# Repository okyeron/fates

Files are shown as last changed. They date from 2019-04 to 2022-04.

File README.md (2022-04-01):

# Important - regarding norns software updates
If you are on a version of norns before 200218 ***DO NOT*** run the on device SYSTEM > UPDATE from the norns menu. 

If you're still on an old version like this - back up your scripts and install from a new (2022) disk image.

# Fates DAC board for Raspberry Pi

Fates is an audio and UI platform for Raspberry Pi 3 Model B+ and Pi 4 Model B that provides a stereo audio codec with headphone driver, 3 (or 4) encoders, 3 buttons, a 128x64 OLED display, 2x audio ins, and 2x audio outs. 

Fates is fully compatible with the [monome norns](<https://github.com/monome/norns>) software ecosystem. A “DIY norns” if you like. Once installed, Fates can be used with the primary norns codebase, without any branches or mods.

Fates can also be used directly with Orac 2.0 (puredata) and also with other Raspberry Pi audio projects like PatchboxOS, etc.

NOTE - this install and norns software has been tested mostly on the Pi3b+ and Pi4b. It may not work perfectly on older/slower Pi models (3b, etc.) and may need different configuration. 

### Specs:

- WM8731 stereo audio codec with headphone driver
- NHD-2.7-12864WDW3 128x64 grayscale OLED display
- 3 pushbuttons
- 3 rotary encoders (optional 4th encoder for Orac or other software)
- 2x 1/8in inputs
- 2x 1/8in outputs
- 1/8in stereo headphone out

Fates was designed for Raspberry Pi 3 Model B+ and Raspberry Pi 4 Model B. It’s not been performance tested with earlier Raspberry PI models.

For Raspberry Pi 4, Fates includes a USB-C power jack which fixes the Pi4 issue with "e-marked" USB-C cables not powering the device.

Fates can be powered either from it's own USB-C power jack, or the Raspberry Pi power jack (but NOT both).

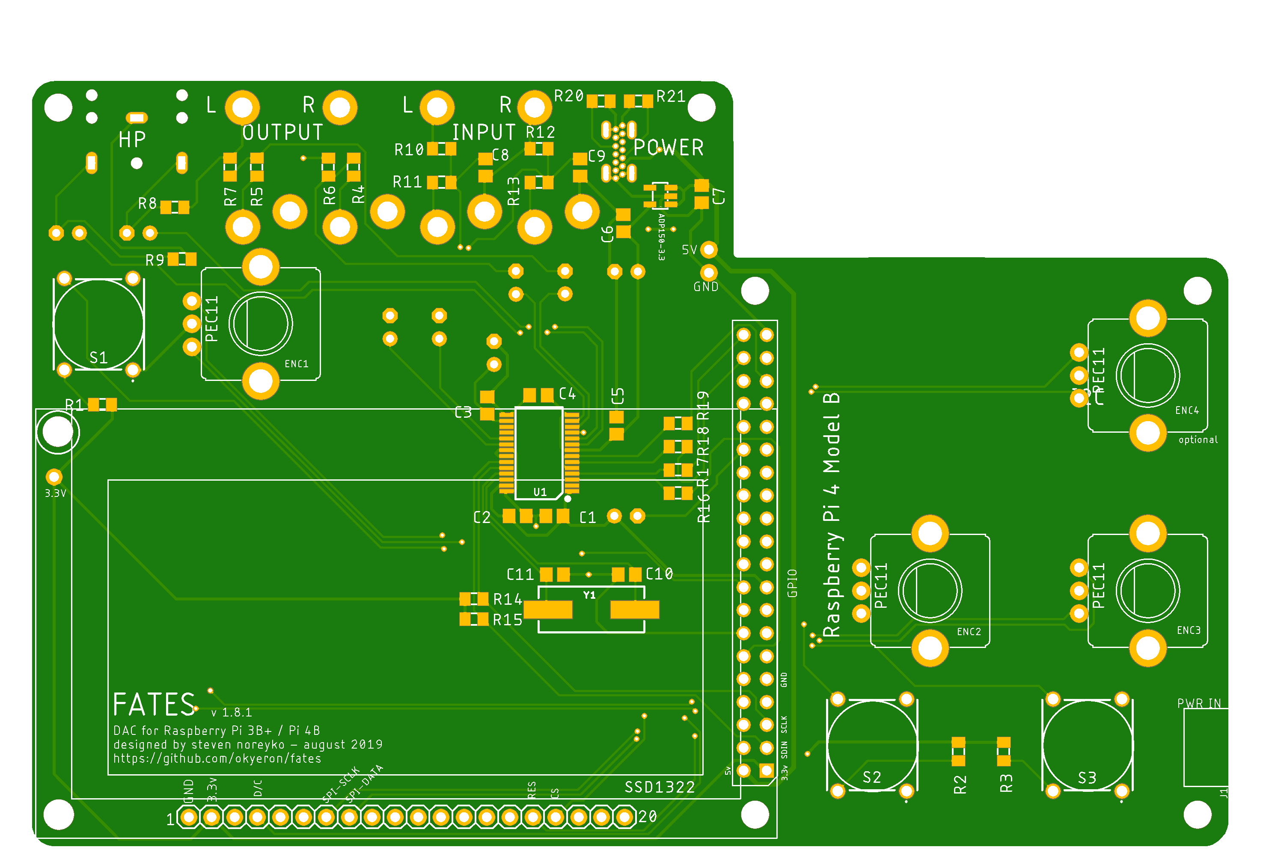
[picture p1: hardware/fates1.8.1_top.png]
<fates pcb top>


## BOM and Build 

[BOM](hardware/BOM.md)  

[BOM - Thru-hole only](hardware/BOM-thruhole.md)  (for SMD assembled boards)

[Build Guide](hardware/Build.md)

[Acrylic Case Assembly](hardware/AcrylicCase.md)

## Install instructions

- [Installing Fates 1.8+ from disk image](https://github.com/okyeron/fates/blob/master/install/norns/Norns_disk_image_install.md) 

## Troubleshooting

[See this troubleshooting doc for more](troubleshooting.md) 

## UART

Fates includes UART pins broken out for a serial connection to another computer using a UART-USB cable.

For example - the [Adafruit 954 cable](https://www.adafruit.com/product/954):
- white lead TX
- green lead RX
- black lead GND
- ***red lead (5v) from the UART cable is not connected on Fates***

Then connect using `screen`

  `screen /dev/cu.usbserial* 115200`

If this does not work, try swapping TX and RX

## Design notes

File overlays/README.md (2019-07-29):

# Fates DAC board for raspberry pi version 1.7+

# Overlays and GPIO assignments

## Key/button GPIO (v1.7+)

- K1 : GPIO 24
- K2 : GPIO 25
- K3: GPIO 23

## Encoder GPIO  (v1.7+)

- E1A : GPIO 5  
- E1B : GPIO 6  

- E2A : GPIO 13  
- E2B : GPIO 12  

- E3A : GPIO 27  
- E3B : GPIO 22 

- E4A : GPIO 26 
- E4B : GPIO 16 

## OLED display  (v1.7+)

- RES : GPIO 4
- DC : GPIO 17

## for reference (this is handled by install script)
```
# compile the overlays (buttons and encoders + ssd1322)
sudo dtc -W no-unit_address_vs_reg -@ -I dts -O dtb -o /boot/overlays/fates-buttons-encoders.dtbo /home/we/fates/overlays/fates1.7-buttons-encoders-overlay.dts
sudo dtc -W no-unit_address_vs_reg -@ -I dts -O dtb -o /boot/overlays/fates-ssd1322.dtbo /home/we/fates/overlays/fates1.7-ssd1322-overlay.dts
```

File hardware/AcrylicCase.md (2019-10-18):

## Fates Acrylic Case Kits

### Standoff guide

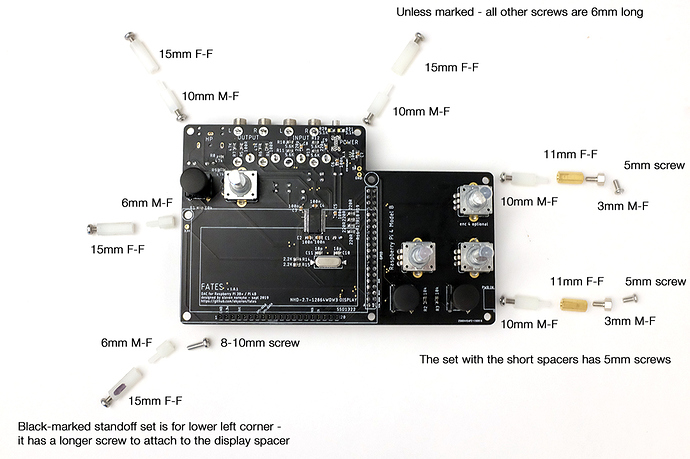
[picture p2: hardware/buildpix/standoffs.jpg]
standoffs


### Assembly

I made an assembly video which you can [watch over on Youtube](https://youtu.be/23gvgvg2Bow)

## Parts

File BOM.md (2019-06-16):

## Fates 1.5 BOM

Some alternate parts are listed with a zero quantity. Choose what works best for you.

PJ302M jacks are available from [Thonk](https://www.thonk.co.uk/shop/3-5mm-jacks/ ), [Synthcube](https://synthcube.com/cart/3-5mm-mono-jack-pj302m-rt-angle-hex-nut) and [Modular Addict](https://modularaddict.com/pj302m-jacks) among other sources.

Raspberry Pi 3B+ can be purchased from a number of sources such as [Adafruit](https://www.adafruit.com/product/3775?src=raspberrypi), [CanaKit](https://www.canakit.com/raspberry-pi-3-model-b-plus.html?cid=usd&src=raspberrypi&src=raspberrypi), [Element14](http://www.newark.com/49AC7637?src=raspberrypi), etc.

| Mouser  | QTY | Part | Value | Package |
|-----|:--:|-----|-----|-----|
||3|R1 R2 R3|10k|0805|
||2|R5 R16|100R|0805|
||2|R7 R8|2.2K|0805|
||4|R4 R20 R22 R26|5.6K|0805|
||4|R6 R18 R32 R33|47K|0805|
||2|C13 C14|18p|0805|
||2|C8 C17|220p|0805|
||7|C1 C6 C11 C22 C23 C25 C27|100n|C0805|
|710-860020672005|4|C9 C7 C4 C12|1uF Electrolytic|11mm|
|667-ECE-A1VKS100|3|C2 C3 C10|10uF Electrolytic|11mm|
|667-ECA-0JM221B|2|C15 C16|220uF Electrolytic|11mm|
|ADP150AUJZ-3.3-R7|1|ADP150-3.3|ADP150AUJZ-3.3-R7||
|238-WM8731SEDS/RV|1|U1|WM8731SEDS/V|SSOP28||
|815-ABLS2-12.2-D4Y-T|1|Y1|12.288MHz|HC49UP||
|652-PEC11R-4015F-N24|3|ENC1 ENC2 ENC3|ENC_BOURNS_PEC11||
|NHD-2.7-12864WDW3|1|SSD1322|NHD-2.7-12864WDW3|
|806-STX-3100-3CB|1|STX3100-5CB|STEREOJACK|
||4|Z5 Z6 Z7 Z8|PJ302M2|PJ302M|
|490-MJ-3536|0| ALT |alternate jack - CUI MJ-3536||
|517-929984-01-20-RK|1||1x20 low profile female header for disp||
|855-M20-9994045|1||1x20 male pin header for disp||
|485-2222|1||2x20 GPIO female header for RasPi|Adafruit Part # 2222|
|649-10027011-106HLF|1||UART pin header||
|538-47642-0001|1||USB Micro jack||
|5GSH920Q|3|S1 S2 S3|5G MEC switch - Quiet||
|5GSH920|0| ALT |5G MEC switch - Clicky||
|642-1US09|3| |5G MEC switch caps black||
|642-1US03|0| ALT |5G MEC switch caps gray||
||1| |RPI3 b+||

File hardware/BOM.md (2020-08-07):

## Fates 1.8+ BOM

Some parts are listed with a zero quantity. This are meant to be alternates (and should be marked with `ALT`). Choose what works best for you.

PJ302M jacks are available from [Thonk](https://www.thonk.co.uk/shop/3-5mm-jacks/ ), [Synthcube](https://synthcube.com/cart/3-5mm-mono-jack-pj302m-rt-angle-hex-nut) and [Modular Addict](https://modularaddict.com/pj302m-jacks) among other sources. Or you can get the alternate CUI MJ-3536 jack listed below from Mouser.

Raspberry Pi 3B+ or 4B can be purchased from a number of sources such as [PiShop.us](https://www.pishop.us/product/raspberry-pi-4-model-b-1gb/), [Adafruit](https://www.adafruit.com/product/3775?src=raspberrypi), [CanaKit](https://www.canakit.com/raspberry-pi-3-model-b-plus.html?cid=usd&src=raspberrypi&src=raspberrypi), [Element14](http://www.newark.com/49AC7637?src=raspberrypi), etc.
Mouser also now carries Pis (although a bit more expensive) if you want one-stop shopping (part numbers listed below).

ENC4 is optional and is not functional for norns right now. If you want to use Orac later, get 4 encoders.

Note - some Mouser part numbers may be out of stock (usually passives), so you may need to search for equivalent alternatives

| Mouser  | QTY | Part | Value | Package |
|-----|:--:|-----|-----|-----|
|603-AC0805FR-07100RL|2|R4 R5|100R|0805|
|603-RC0805FR-07220RL|4|R16 R17 R18 R19|220R|0805|
|660-RK73H2ATTD2201F|2|R14 R15|2.2K|0805|
|603-RC0805FR-075K1L|2|R20 R21|5.1K|0805|
|279-CRGCQ0805F5K6|4|R10 R11 R12 R13|5.6K|0805|
|603-RC0805FR-0710KL|3|R1 R2 R3|10k|0805|
|RC0805FR-0747KL|4|R6 R7 R8 R9|47K|0805|
|603-CC805JRNPO9BN180|2|C10 C11|18p|0805|
|710-885012207082|2|C8 C9|220p|0805|
|80-C0805C104J5RACLR|7|C1 C2 C3 C4 C5 C6 C7|100n|0805|
|710-860020672005|4|C12 C13 C14 C15|1uF Electrolytic|11mm|
|667-ECE-A1VKS100|3|C18 C19 C20|10uF Electrolytic|11mm|
|80-ESH227M016AE3AA|2|C16 C17|220uF Electrolytic|11mm| 
|ADP150AUJZ-3.3-R7|1|ADP150-3.3|ADP150AUJZ-3.3-R7||
|238-WM8731SEDS/RV|1|U1|WM8731SEDS/V|SSOP28||
|815-ABLS2-12.2-D4Y-T|1|Y1|12.288MHz|HC49UP||
|652-PEC11R-4015F-N24|3|ENC1 ENC2 ENC3 (ENC4)|15mm Flatted shaft||
|652-PEC11R-4015K-N24|0|ALT ENC1 ENC2 ENC3 (ENC4)|15mm Knurled shaft||
|652-PEC11R-4020F-N24|0|ALT ENC1 ENC2 ENC3 (ENC4)|20mm Flatted shaft||
|NHD-2.7-12864WDW3|1|SSD1322|NHD-2.7-12864WDW3 OLED Display|
|490-SJ1-3523N|1|CUI_SJ1-3523N|STEREOJACK Headphone||
||4|Z5 Z6 Z7 Z8|PJ302M2 1/8in mono jack|PJ302M|
|490-MJ-3536|0| ALT |alternate 1/8in jack - CUI MJ-3536||
|517-929984-01-20-RK|1||1x20 low profile female header for disp||
|200-SLW12001TS|0|ALT|1x20 low profile female header for disp||
|855-M20-9992045|1||1x20 male pin header for disp (gold)||
|855-M20-9992046|0|ALT|1x40 male pin header for disp (tin)||
|485-2222|1||2x20 GPIO female header for RasPi|Adafruit Part # 2222|
|855-M20-7832046|0|ALT|Alternate 2x20 GPIO female header||
|649-10027011-106HLF|1||UART 6 pin header||
|806-KUSBX-SLCS1N14-B|1||USB C jack|** See note|
|5GTH920|3|S1 S2 S3|5G MEC switch - Clicky||
|5GTH920Q|0|S1 S2 S3 ALT|5G MEC switch - Quiet||
|642-1US09|3| |5G MEC switch caps black||
|642-1US03|0| ALT |5G MEC switch caps gray||
|642-1DS09|0| ALT |5G MEC switch caps black - rounded||
|[RPI3-MODBP-BULK](http://www.mouser.com/Search/ProductDetail.aspx?R=RPI3-MODBP-BULK)|1| |RPI3 b+||
|[RPI4-MODBP-2GB-BULK](http://www.mouser.com/Search/ProductDetail.aspx?R=RPI4-MODBP-2GB-BULK)|0| |RPI4 b 2GB||
|[RPI4-MODBP-4GB-BULK](http://www.mouser.com/Search/ProductDetail.aspx?R=RPI4-MODBP-4GB-BULK)|0| |RPI4 b 4GB||
||1| |RPI Power supply - 3A USB-C recommended||

If out of stock at Mouser/Digikey, the OLED display can also be purchased [directly from the manufacturer here](https://www.newhavendisplay.com/nhd2712864wdw3-p-9547.html).

You might need to adjust order quantities, get knurled encoders, or get clicky buttons instead of quiet. So be sure to check part numbers and availability before ordering. NOTE - some parts may be out of stock. See the alternates listed above for other choices.

\** The USB-C jack can be considered optional. You can power everything directly from the Raspberry Pi's own power input OR the Fates USB-C jack (DO NOT TRY TO POWER BOTH!)

**[A mouser cart](https://www.mouser.com/ProjectManager/ProjectDetail.aspx?AccessID=bdba42bdf9 )** is setup with these parts (not including Pi). **Audio jacks are NOT INCLUDED in this cart** (see note above). If you want them from Mouser order 4 of 490-MJ-3536

**NOTE - Mouser cart likely has items out of stock right now.** Check above for alternate part numbers.

## Spacers/screws

**NOTE - If you're getting an acrylic case from the Denki-oto shop, the case kit includes spacers/screws.**

Spacers/screws are also not included in the cart above. There is a [separate cart for spacers](https://www.mouser.com/ProjectManager/ProjectDetail.aspx?AccessID=367d290c06) if you need them (**Cart does not include screws**).

Spacers/screws - I use 2.5mm size screws and spacers. 3mm should work as well.

Here's my spacer list. This may also be to taste if you solder the display header closer to the main board. Sorry I don't have a good Mouser part number for 2.5M screws.

| | qty | height |  | location  |
|-----|--|-----|-----|-----|
|[855-R25-3000302](http://www.mouser.com/Search/ProductDetail.aspx?R=855-R25-3000302)|2|3mm|M-F|Right side pi bottom|
|[761-M2101-2545-AL](http://www.mouser.com/Search/ProductDetail.aspx?R=761-M2101-2545-AL)|2|6mm|M-F|under oled display corners|
|[761-M1258-2545-AL](http://www.mouser.com/Search/ProductDetail.aspx?R=761-M1258-2545-AL)|2|11mm|F-F|Right side pi|
|[761-M1262-2545-AL](http://www.mouser.com/Search/ProductDetail.aspx?R=761-M1262-2545-AL)|4|15mm|F-F|left/back side|
|[761-M2105-2545-AL](http://www.mouser.com/Search/ProductDetail.aspx?R=761-M2105-2545-AL)|4|10mm|M-F|top corners|
||2||5mm long|2.5mm rack screws|
||10||6mm long|2.5mm rack screws|
||1||8-10mm long|2.5mm rack screws|

### encoder knobs:

 https://modularaddict.com/parts/knobs/reanp670d-knobs  
 https://store.djtechtools.com/products/chroma-caps-knobs-and-faders  
 https://synthcube.com/cart/synth-diy/parts/knobs/rogan-series-p-knobs  
 https://modularaddict.com/parts/knobs/pt2d-knob  
 https://modularaddict.com/parts/knobs/albs-midibox-knobs

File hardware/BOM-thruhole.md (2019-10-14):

## Fates 1.8+ BOM - Thru Hole Only (for those with a pre-smd-soldered pcb)

Some parts are listed with a zero quantity. This are meant to be alternates (and should be marked with `ALT`). Choose what works best for you.

Raspberry Pi 3B+ or 4B can be purchased from a number of sources such as [PiShop.us](https://www.pishop.us/product/raspberry-pi-4-model-b-1gb/), [Adafruit](https://www.adafruit.com/product/3775?src=raspberrypi), [CanaKit](https://www.canakit.com/raspberry-pi-3-model-b-plus.html?cid=usd&src=raspberrypi&src=raspberrypi), [Element14](http://www.newark.com/49AC7637?src=raspberrypi), etc.
Mouser also now carries Pis (although a bit more expensive) if you want one-stop shopping (part numbers listed below).

ENC4 is optional and is not functional for norns right now. If you want to use Orac later, get 4 encoders.

| Mouser  | QTY | Part | Value | Package |
|-----|:--:|-----|-----|-----|
|710-860020672005|4|C12 C13 C14 C15|1uF Electrolytic|11mm|
|667-ECE-A1VKS100|3|C19 C20 C21|10uF Electrolytic|11mm|
|667-ECA-0JM221B|2|C17 C18|220uF Electrolytic|11mm| 
|652-PEC11R-4015F-N24|3|ENC1 ENC2 ENC3 (ENC4)|15mm Flatted shaft||
|652-PEC11R-4015K-N24|0|ALT ENC1 ENC2 ENC3 (ENC4)|15mm Knurled shaft||
|652-PEC11R-4020F-N24|0|ALT ENC1 ENC2 ENC3 (ENC4)|20mm Flatted shaft||
|NHD-2.7-12864WDW3|1|SSD1322|NHD-2.7-12864WDW3 OLED Display|
|490-SJ1-3523N|1|CUI_SJ1-3523N|STEREOJACK Headphone||
|517-929984-01-20-RK|1||1x20 low profile female header for disp||
|200-SLW12001TS|0|ALT|1x20 low profile female header for disp||
|855-M20-9992045|1||1x20 male pin header for disp (gold)||
|855-M20-9992046|0|ALT|1x40 male pin header for disp (tin)||
|485-2222|1||2x20 GPIO female header for RasPi|Adafruit Part # 2222|
|855-M20-7832046|0|ALT|Alternate 2x20 GPIO female header||
|649-10027011-106HLF|1||UART 6 pin header||
|5GTH920|3|S1 S2 S3|5G MEC switch - Clicky||
|5GTH920Q|0|S1 S2 S3 ALT|5G MEC switch - Quiet||
|642-1US09|3| |5G MEC switch caps black||
|642-1US03|0| ALT |5G MEC switch caps gray||
|642-1DS09|0| ALT |5G MEC switch caps black - rounded||
|[RPI3-MODBP-BULK](http://www.mouser.com/Search/ProductDetail.aspx?R=RPI3-MODBP-BULK)|1| |RPI3 b+||
|[RPI4-MODBP-2GB-BULK](http://www.mouser.com/Search/ProductDetail.aspx?R=RPI4-MODBP-2GB-BULK)|0| |RPI4 b 2GB||
|[RPI4-MODBP-4GB-BULK](http://www.mouser.com/Search/ProductDetail.aspx?R=RPI4-MODBP-4GB-BULK)|0| |RPI4 b 4GB||
||1| |RPI Power supply - 3A USB-C recommended||

You might need to adjust order quantities, get knurled encoders, or get clicky buttons instead of quiet. So be sure to check part numbers and availability before ordering. NOTE - some parts may be out of stock. See the alternates listed above for other choices.

**[A mouser cart](https://www.mouser.com/ProjectManager/ProjectDetail.aspx?AccessID=c39648324f )** is setup with these parts (not including Pi). 

**NOTE - Mouser cart likely has items out of stock right now.** Check above for alternate part numbers.

Spacers/screws are also not included in this cart. There is a [separate cart for spacers](https://www.mouser.com/ProjectManager/ProjectDetail.aspx?AccessID=367d290c06) if you need them (**Cart does not include screws**).

## Spacers/screws

**NOTE - If you're getting an acrylic case from the Denki-oto shop, the case kit includes spacers/screws.**

Spacers/screws - I use 2.5mm size screws and spacers. 3mm should work as well.

Here's my spacer list. This may also be to taste if you solder the display header closer to the main board. Sorry I don't have a good Mouser part number for 2.5M screws.

| | qty | height |  | location  |
|-----|--|-----|-----|-----|
|[855-R25-3000302](http://www.mouser.com/Search/ProductDetail.aspx?R=855-R25-3000302)|2|3mm|M-F|Right side pi bottom|
|[761-M2101-2545-AL](http://www.mouser.com/Search/ProductDetail.aspx?R=761-M2101-2545-AL)|2|6mm|M-F|under oled display corners|
|[761-M1258-2545-AL](http://www.mouser.com/Search/ProductDetail.aspx?R=761-M1258-2545-AL)|2|11mm|F-F|Right side pi|
|[761-M1262-2545-AL](http://www.mouser.com/Search/ProductDetail.aspx?R=761-M1262-2545-AL)|4|15mm|F-F|left/back side|
|[761-M2105-2545-AL](http://www.mouser.com/Search/ProductDetail.aspx?R=761-M2105-2545-AL)|4|10mm|M-F|top corners|
||2||5mm long|2.5mm rack screws|
||10||6mm long|2.5mm rack screws|
||1||8-10mm long|2.5mm rack screws|

### encoder knobs:

 https://modularaddict.com/parts/knobs/reanp670d-knobs  
 https://store.djtechtools.com/products/chroma-caps-knobs-and-faders  
 https://synthcube.com/cart/synth-diy/parts/knobs/rogan-series-p-knobs  
 https://modularaddict.com/parts/knobs/pt2d-knob  
 https://modularaddict.com/parts/knobs/albs-midibox-knobs

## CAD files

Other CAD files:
hardware/fates-panels-v1.8-4enc.dxf
hardware/fates-panels-v1.8-3enc.dxf

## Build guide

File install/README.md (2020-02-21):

# Fates DAC board for raspberry pi

See:

- [Installing Fates 1.8+ from disk image](https://github.com/okyeron/fates/blob/master/install/norns/Norns_disk_image_install.md) **(recommended)**  

- [Installing Norns on Fates  1.8+ (Full Install Procedure)](https://github.com/okyeron/fates/blob/master/install/norns/Norns_install_instructions_1.8.md)

# Important - regarding norns software updates
If you are on a version of norns before 200218 ***DO NOT*** run the on device SYSTEM > UPDATE from the norns menu. 

You will need to update manually. [See here](https://github.com/fates-project/norns/releases)

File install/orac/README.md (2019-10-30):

# Fates DAC board for raspberry pi

# Orac BETA 

Everything here depends on having a working norns setup. Please see that installation first.

NOTE - This thread on the lines forum is the best place to get information on running Orac on Fates.

Installation information is in the Top Post:

https://llllllll.co/t/orac-sidekick-and-pure-data-for-norns/26198

### Video:

https://youtu.be/Ukzc3W_lcjk

### Download

Orac, Sidekick - https://patchstorage.com/orac-2-0-for-norns/ 

### Demo Pure Data apps featured in Video

SimplePd - https://patchstorage.com/simple-demo-patch-for-norns/ 1
PolyPd - https://patchstorage.com/polypd-for-norns/

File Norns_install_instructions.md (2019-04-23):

# Installing Norns on NordHat
***Nord Hat Rev2 only. If you wish to follow the instructions on another device you should modify the overlay files and config.txt accordingly***

## Preparing the Raspberry PI

### Download raspbian stretch lite
https://www.raspberrypi.org/downloads/raspbian/  

### Flash raspbian lite to the sdcard
Use balenaEtcher - https://www.balena.io/etcher/ for this.

### SSH configuration

 Create a **wpa-supplicant.conf** file for your network and copy the file to the root of the ***boot*** volume

    country=fr (your country)
    update_config=1
    ctrl_interface=/var/run/wpa_supplicant
    network={
      scan_ssid=1
      ssid="Name of your router"
      psk="Your key"
    }

Open a terminal and type paste the following commands, one line at a time:

    cd /volumes && ls
    cd boot && touch ssh

Move the **wpa-supplicant.conf** file you've created to the root of the SD card and then unmount the sd card.

### Mount the SD card and boot the Raspberry Pi

Find the IP of your Raspberry Pi using a software like [Lanscan](https://itunes.apple.com/us/app/lanscan/id472226235) (on MacoS) and then 
   generate a key (replace XX with the IP of the RPI).  
Open a terminal and enter the following command (XX is the last two digits of the PI's IP).  
`ssh-keygen -R 192.168.1.XX`

Connect via SSH. `ssh pi@192.168.1.XX` The password is ***raspberry***

### RPI adjustments
Enter the following commands in a terminal, edit if needed (country etc).

`sudo raspi-config nonint do_hostname norns`  
`sudo raspi-config nonint do_spi 0`  
`sudo raspi-config` (change wifi country in the "Localization" menu, this is crucial)  
`sudo raspi-config nonint do_expand_rootfs`  
`sudo su`  
`passwd pi` ***(sleep)***  
`sudo reboot`  
`ssh keygen -R norns.local`  
`sudo passwd root` ***(sleep)***  
`sudo nano /etc/ssh/sshd_config` ***("PermitRootLogin" needs to be set to "yes" and uncomment the line)***  
`sudo reboot`  
`ssh root@norns.local`  
`usermod -l we -d /home/we -m pi`   
`groupmod --new-name we pi`  
`exit`  
`ssh we@norns.local`  
`sudo passwd -l root` ***(sleep)***
`sudo nano /etc/sudoers.d/010_pi-nopasswd` ***(change pi to we)***  
`sudo reboot`

## Linux & Kernel

### Run updates install git, build dependencies, etc
Reminder: the password is ***sleep***  

    ssh we@norns.local
	sudo apt-get update
    sudo apt-get dist-upgrade -y
    sudo apt-get install vim git bc i2c-tools -y
    git clone https://github.com/nordseele/nordhat.git
    cd /home/we/nordhat/install/norns/scripts && ./hat_prepare.sh

### Testing the ssd1322
Now we're going to test the display. If your soldering is fine and if the kernel has been built correctly, you should see the console displayed on the OLED screen but first we need to do this :

    sudo modprobe fbtft_device custom name=fb_ssd1322 width=128 height=64 speed=16000000 gpios=reset:25,dc:24
    con2fbmap 1 1

## Norns
    cd /home/we/nordhat/install/norns/scripts &&./hat_packages.sh

You will be disconnected and the device will reboot. Reconnect in a new window.  

    cd /home/we/nordhat/install/norns/scripts &&./hat_install.sh
Answer ***yes (y)*** to "enable realtime priority"

## Wifi network  
*Do this manually, too risky to put it in the script.*

    ssh we@norns.local
    sudo cp ~/norns-linux-bits/interfaces /etc/network/interfaces
    sudo mv /etc/wpa_supplicant/wpa_supplicant.conf /etc/wpa_supplicant/wpa_supplicant_bak.conf

And reboot (with command line if possible).  
On the Raspberry pi, navigate to System -> Wifi and add your network manually.

## Audio configuration
*(this part needs to be tested once again)*

    ssh we@norns.local
    amixer controls
    amixer cset numid=13 on #Output Mixer HiFi  
    amixer cset numid=4 on #line in  
    sudo alsactl store  
    amixer cset numid=3 0%

    sudo reboot

*N.B: These install instructions are based on the work of Tehn, Okyeron, The Technobear among others. Thank you!*

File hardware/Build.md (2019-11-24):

## Fates 1.8+ Build

This is an intermediate to advanced build. If you've not soldered a TSSOP chip before (the DAC), this build may be challenging. Seek assistance if possible.

Everything is marked on the pcb, but if you need help, please see below for parts placement  

### DAC

Solder the DAC first. Use flux. Google some videos if you're not sure how best to solder it.
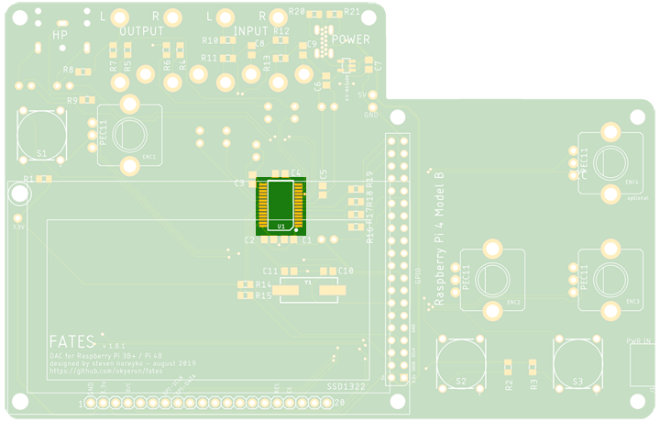
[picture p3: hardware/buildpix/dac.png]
dac


### Voltage regulator
Do the little voltage regulator next and then check your work on all those tiny pins with a loupe/magnifier.

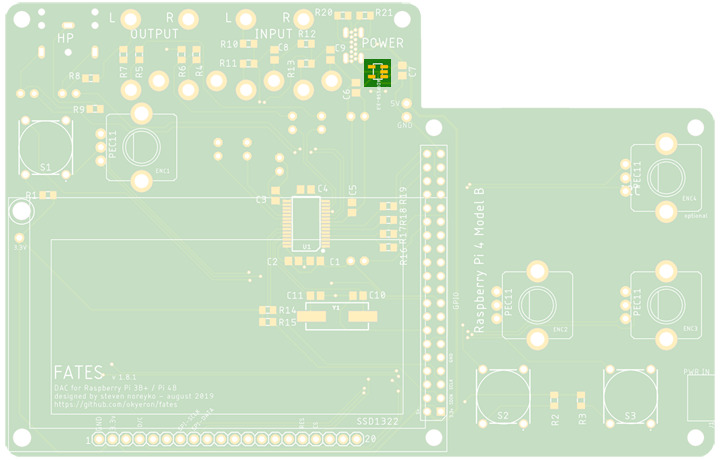
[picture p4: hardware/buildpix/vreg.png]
vreg


### 100n capacitors  
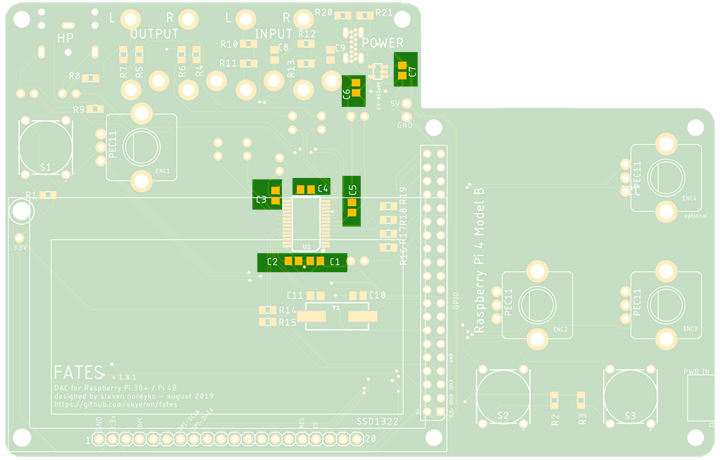
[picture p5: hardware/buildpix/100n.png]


### 220p capacitors  
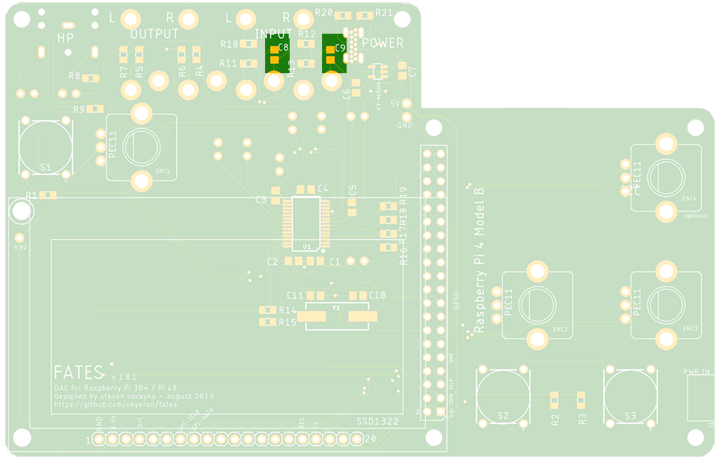
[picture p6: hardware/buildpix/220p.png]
220p capacitors


### 18p capacitors  
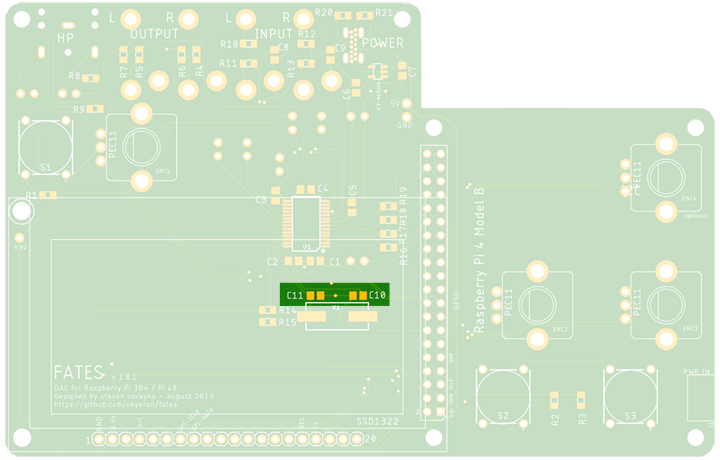
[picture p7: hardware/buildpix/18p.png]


### 100R resistors  
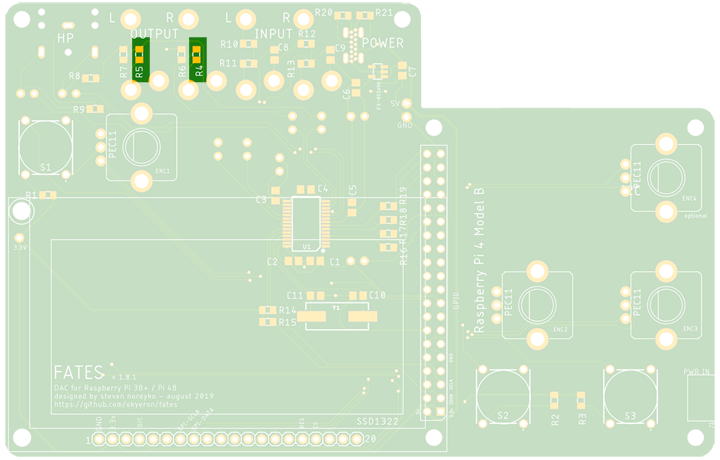
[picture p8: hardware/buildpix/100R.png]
100R resistors


### 220R resistors  
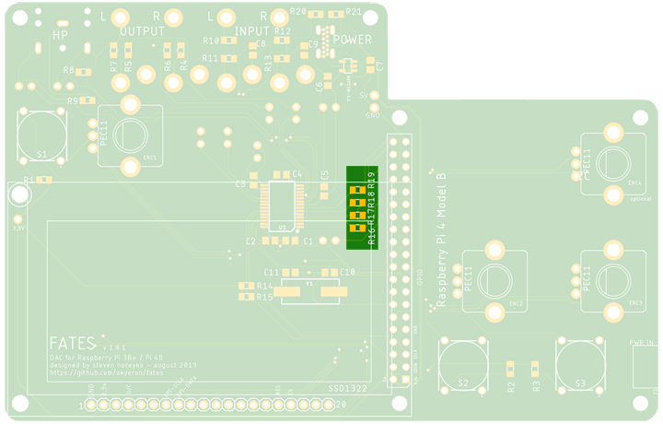
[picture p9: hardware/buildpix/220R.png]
220R resistors


### 2.2K resistors  
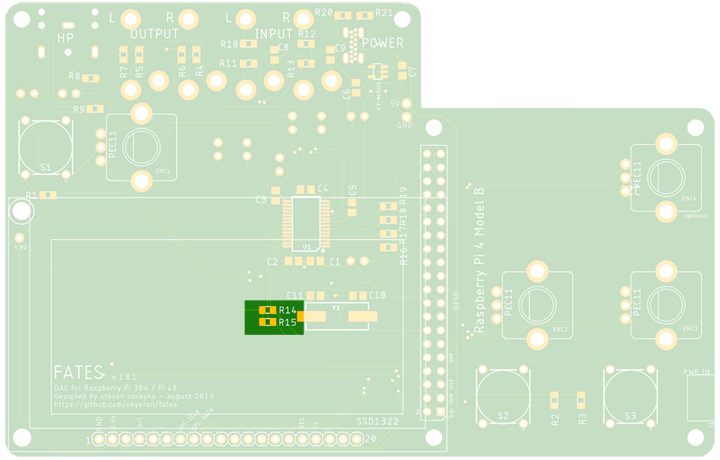
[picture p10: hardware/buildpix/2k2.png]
2k2 resistors


### 5.1K resistors  
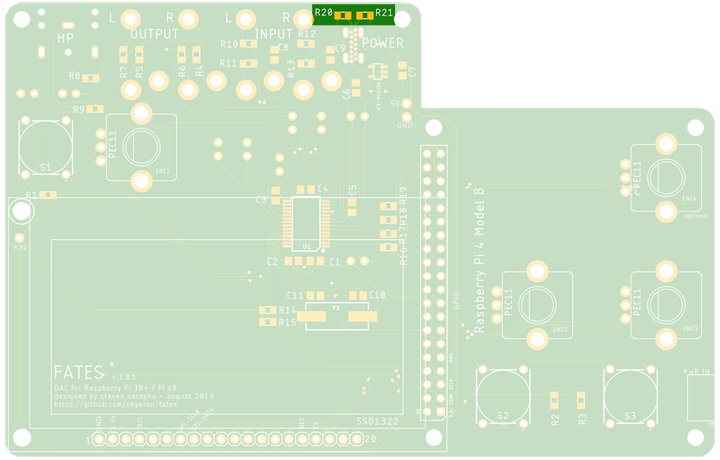
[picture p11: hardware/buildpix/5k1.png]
5k1 resistors


### 5.6K resistors  
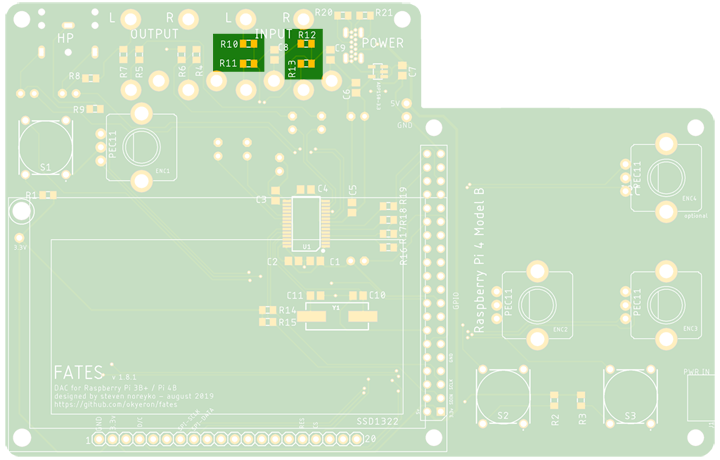
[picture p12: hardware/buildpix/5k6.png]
5k6 resistors


### 10K resistors  
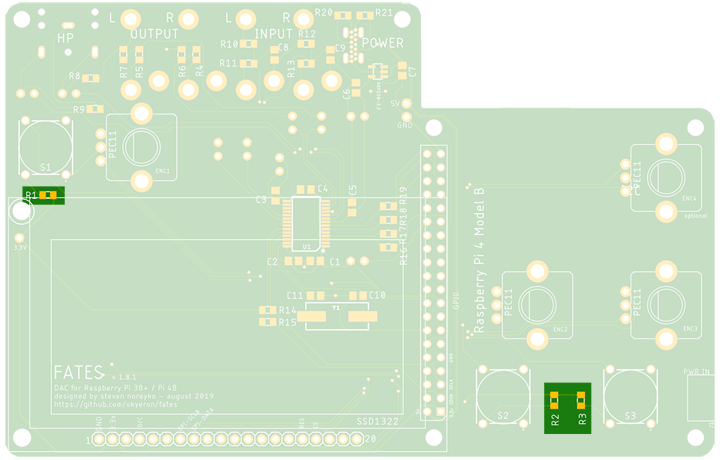
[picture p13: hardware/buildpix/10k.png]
10k resistors


### 47K resistors  
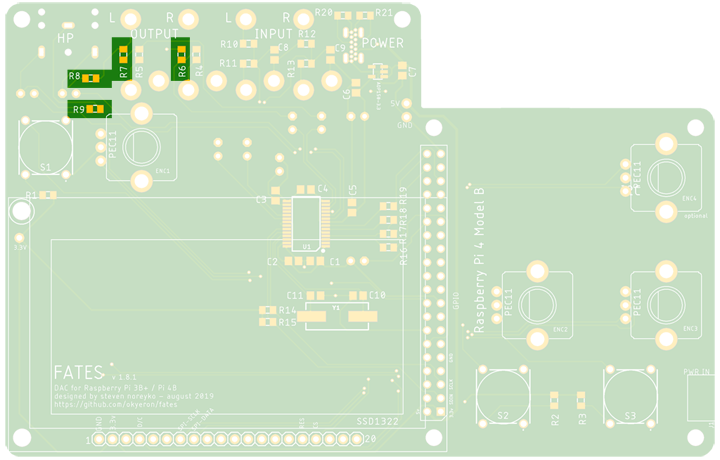
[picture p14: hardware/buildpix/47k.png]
47k resistors


### Crystal
Save the crystal for last of the smd stuff since it's big and gets in the way of soldering the smaller parts.

There's no direction or polarity here. It can go on either way.

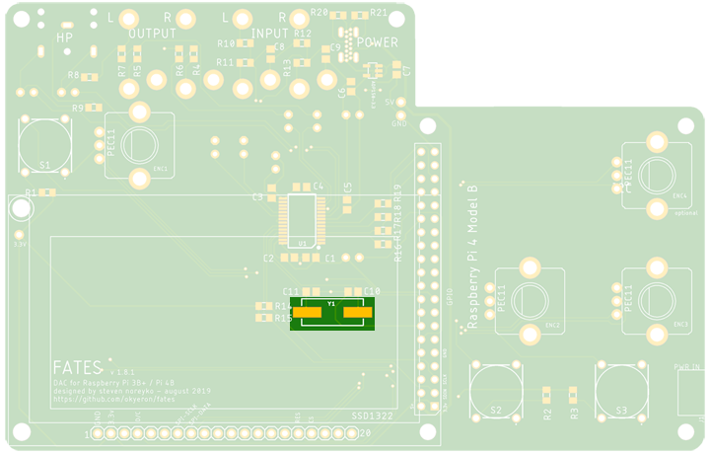
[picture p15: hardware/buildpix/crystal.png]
crystal


# Thru-hole

I have been doing the thru-hole stuff in the following order: USB jack, audio jacks, headphone jack, pin headers (2x20 first, then flip over for the 1x20), switches, capacitors, and encoders last. Then do the headers on the display.

## USB-C Jack 

The pins here are quite small and close together. 

**Be extra careful inserting the jack onto the pcb.** I've bent the little pins more than once. **Before you solder** - check from the top with a loupe/magnifier to be sure each hole has a pin in it.

Solder each pin and then hit the area with some flux and touch each point again.

Be aware of the routing on the USB Jack pins. Some pins are tied together, so don't be alarmed if your soldering looks bridged on the diagonals.  

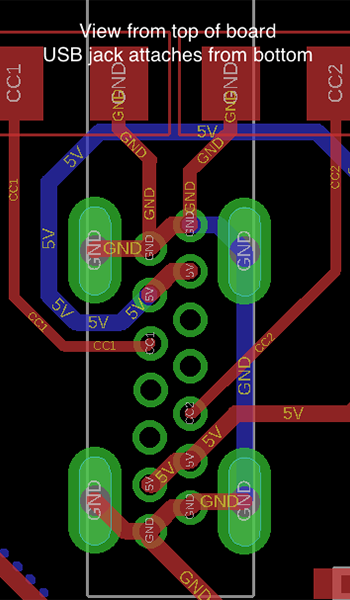
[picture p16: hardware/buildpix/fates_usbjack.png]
USB Jack

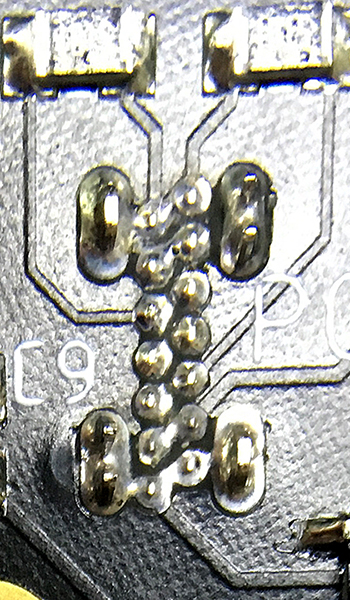
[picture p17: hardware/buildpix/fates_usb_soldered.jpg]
USB Soldering


## TIP - Test voltage

Once the USB-C jack is attached, check that you don't have continuity between 5v and GND and then plug power into the jack and check the USB-C power input voltage level. I suggest doing this __before__ you attach the pi. There's a 5v/GND header pin holes right near the voltage regulator which is great for testing voltage (+5v).

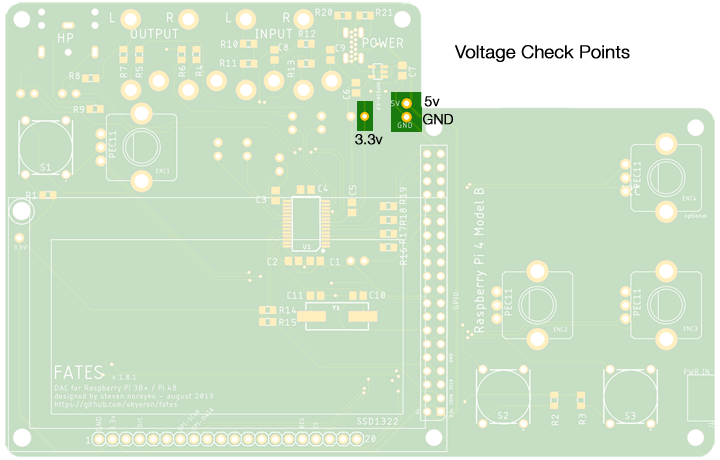
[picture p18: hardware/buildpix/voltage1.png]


***Be sure you are using a good power supply. The Pi 3b+ needs a 5V 2.5A power supply. The Pi 4 requires a 5V 3A power supply. Buy one of the official Raspberry Pi power supplies if you're not sure.***

## Audio jacks

Audio jacks (and headphone jack) mount __from the bottom__

NOTE - if you use the CUI MJ-3536 jacks from Mouser, you may need to trim or file the pins to fit in the pcb. The CUI jack pins are just a tiny bit wider than the PJ302M jacks.

## Thru-hole capacitors

These all attach from the bottom. Values are marked on the board. 

NOTE - the caps have polarity. The long pin of the capacitor is the positive pin (+) (this is marked on the board as +). The negative pin (-) is marked on the capacitor as a stripe down the side.

## Headers

The 2x20 (for the pi) goes in from the bottom.

The 1x20 (for the display) goes in from the top.

## Switches (buttons)

Pin 1 is marked on the bottom of the switches. Pin 1 on the pcb is the lower right corner - there's a very small dot there.

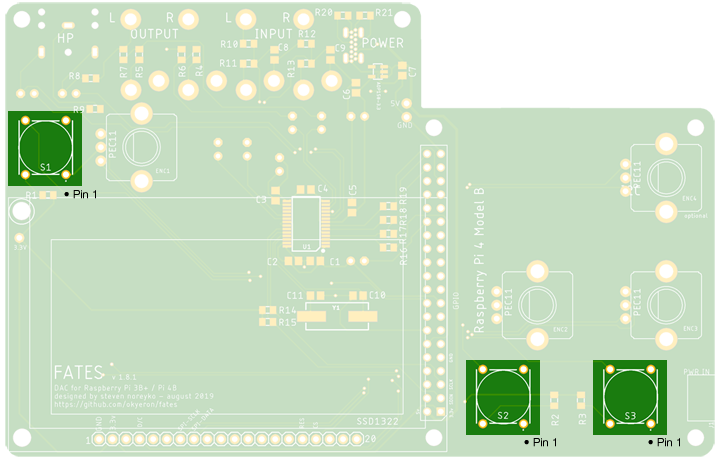
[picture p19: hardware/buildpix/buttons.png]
buttons


## Encoders

Do these last. Don't worry about mounting nuts/washers

## Display header pins

NOTE - Don't solder the display directly to the Fates pcb. Use the low profile header listed in the BOM. You won't want to desolder 20 pins to remove it if something goes wrong with the display.

I use the following method for the display pins - insert the long end of the header pins from the top of the display and then solder them in place from the bottom. Then clip the short header pins from the top.

This ends up with about 6mm between the main board and the display carrier board. You could trim the pins if you want the display to sit lower. My case designs include a 6mm standoff for this mounting technique.

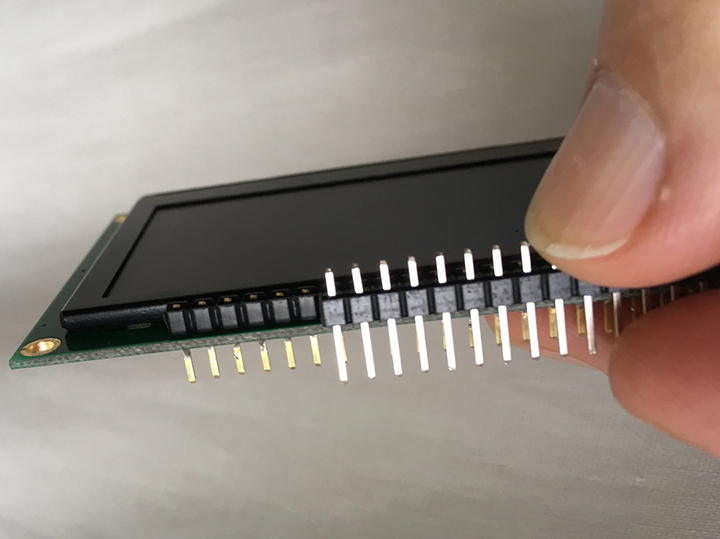
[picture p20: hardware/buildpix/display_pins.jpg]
<display_pins> display pins

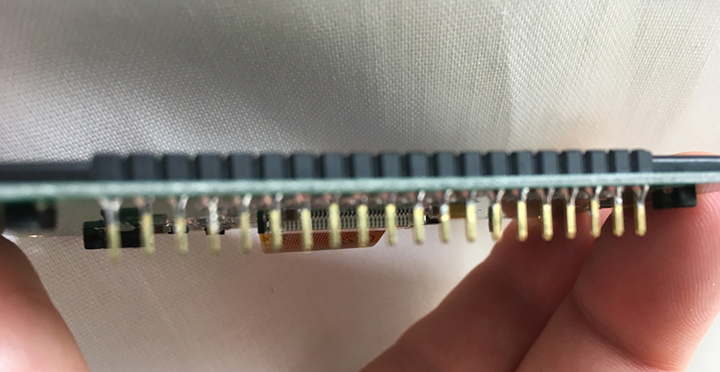
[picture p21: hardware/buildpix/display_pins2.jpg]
<display_pins2> display pins


## TIP - Test voltage again

You can attach the Pi and power it without an SD card inside and then test voltages on the board

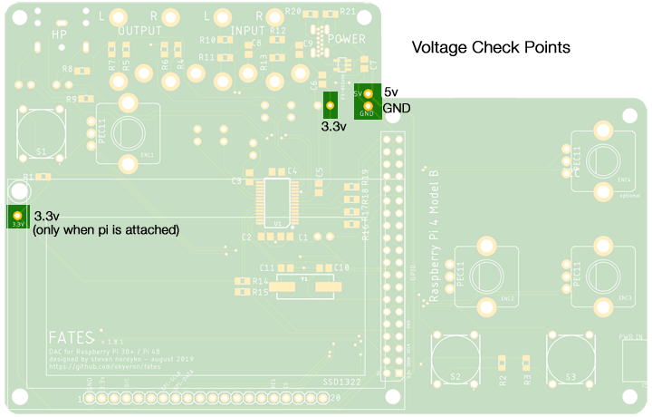
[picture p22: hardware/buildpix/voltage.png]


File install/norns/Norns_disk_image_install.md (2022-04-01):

# Important - Updates
If you are running the norns software prior to 200218 ***DO NOT*** run the on device SYSTEM > UPDATE from the norns menu.  Back up your work and flash with the new disk images below.

Starting with Norns Update 220306 or 220321 - A new disk image is required.

# Installing from disk image
***For Fates v1.8 pcb or later***

### Download Fates disk image (for pi3 or pi4) 

For Raspberry Pi 3b+ 
[img file](https://archive.org/details/fates-pi3b-20220328.img)  (2.9GB)  

For Raspberry Pi 4b 
[img file](https://archive.org/details/fates-pi4b-20220328.img) (2.6GB)  

### Flash disk image to the sdcard
Use balenaEtcher - https://www.balena.io/etcher/ 

When etcher is finished it will unmount your SD card. 

Remove the SD card and insert into your pi/fates and power it up.

## Wifi   

Use the norns menu to navigate to `SYSTEM > WIFI` and add your WiFi network manually.

Use the `ADD` option to choose your network and enter your password, etc.

## norns wifi hotspot

Alternately you can setup the pi as a hotspot from the menu. Once you select that you need to connect to the hotspot network called `norns` with your computer. the password is `nnnnnnnn`

## SSH to the pi

Open a terminal, SSH to the Pi

The default norns user is `we`

The default password is `sleep`

Thus to connect you will use `ssh we@fates.local` (or the IP address of the device) and enter `sleep`

## Expand filesystem

*** this is super important ***

Open a terminal, SSH to the Pi and do

    sudo raspi-config

Then go to `Advanced Options` and select the first option to `Expand Filesystem`.

Then do `Finish` and reboot.

If this errors and says the filesystem can't be resized, try the following from the command line:

    sudo raspi-config --expand-rootfs
    sudo resize2fs /dev/mmcblk0p2

Then reboot.

NOTE - Ignore the warning to reboot after the `--expand-rootfs` command. The resize2fs will take a minute or two to run. Wait for it.

## Set your timezone, wifi-country

Open a terminal, SSH to the Pi and do

    sudo raspi-config
    
first go to `Localization Options` menu item and select `Change Timezone`  
then repeat with `Change WiFi Country`  
	
`Finish` and reboot (if not prompted).  

After these changes, 2 things may happen:

1. You get a `SUPERCOLLIDER FAIL` error at the top of the screen. In this case use the norns menu to SLEEP (which shuts the pi down) and then when the led stops flashing, unplug and plug in power once more to restart. At which point you should see option 2 below. 

2. You see `NONE` listed at the top of the screen. This is normal. Just go to SELECT > AWAKE to start the Awake script.  

## Update

Run SYSTEM > UPDATE on device to update to the current release

## Norns documentation

https://monome.org/docs/norns/

Be sure to check out the section on the [web-based editor maiden](https://monome.org/docs/norns/#maiden). 

Maiden is extremely useful to get debug information if something is going wrong with the norns software. Its interface is arranged into a left sidebar FILE navigator and a right split editor, where the top is the EDITOR and the bottom is the REPL (read-eval-print-loop).

## Norns scripts  

You can find scripts/patches for norns on the [lines forum](https://llllllll.co/c/library)

Scripts are installed at `~/dust/code` The easiest way to install is by using `git clone` from the linux command line as most of the scripts are hosted on github.

for example

```
cd ~/dust/code
git clone https://github.com/justmat/foulplay.git
```
will install the Foulplay script by @justmat

## Norns extras

There are 2 extra scripts installed at in the `~/` home directory - `norns-restart.sh` and `norns-stopall.sh`. These can be used to restart all of the norns software components or stop all those processes (matron, crone/supercollider, JACK, and maiden).

*These install instructions are based on the work of Tehn, Nordseele, Thetechnobear among others. Thank you!*

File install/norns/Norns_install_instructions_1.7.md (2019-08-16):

# Installing Norns on Fates
***For Fates v1.7 pcb or later***

## Preparing the Raspberry PI

### Download Raspbian Buster Lite (for pi3 or pi4) 

https://www.raspberrypi.org/downloads/raspbian/  

### Flash raspbian lite to the sdcard
Use balenaEtcher - https://www.balena.io/etcher/ for this.

When etcher is finished it will unmount your SD card. Remove the SD card and re-insert/mount it in your computer for the next steps.

### SSH and WiFi configuration

The following assumes a "headless" situation without a keyboard or monitor attached to the pi. If you have a keyboard and monitor setup, use `sudo raspi-config` and set up wifi and ssh there. 

Create an empty file named `ssh` (lowercase, and be sure there's no file extension)

Next create a `wpa-supplicant.conf` file with your local wifi network settings. Change the country, router name, and key in the example below.

    country=US #(your country)
    update_config=1
    ctrl_interface=DIR=/var/run/wpa_supplicant GROUP=netdev
    network={
      scan_ssid=1
      ssid="Name of your router"
      psk="Your key"
      key_mgmt=WPA-PSK
    }

Then copy the **wpa-supplicant.conf** and **ssh** files you've created to the root of the ***boot*** volume on the SD card and then unmount the card.

Alternately you can connect to the pi over ethernet and then setup wifi with `raspi-config`. NOTE that you still need the `ssh` file to do this.

### Put the SD card in the Raspberry Pi and boot

Find the IP of your Raspberry Pi using a software like [Lanscan](https://itunes.apple.com/us/app/lanscan/id472226235) (on MacoS)
   
Or if you have a keyboard and HDMI monitor plugged into the pi, login and use `ifconfig` to get your IP address `inet` (you want the one listed under `wlan0`).

(Optional)
Then you can generate an SSH key (replace XX below with the IP of the RPI).  
Open a terminal and enter the following command (XX is the last two digits of the PI's IP).  
`ssh-keygen -R 192.168.1.XX`

Connect via SSH. `ssh pi@192.168.1.XX` The default password is ***raspberry***

`ssh pi@raspberrypi.local` may also work if you have BonJour/ZeroConf available.

### RPI adjustments
Enter the following commands in a terminal, edit if needed (country etc).

Note - a fair bit of this setup is to get the pi to behave exactly like a hardward norns unit (default username/password, etc.)

`sudo raspi-config nonint do_spi 0`  
`sudo raspi-config nonint do_i2c 0`  
`sudo raspi-config nonint do_expand_rootfs`  
`sudo raspi-config nonint do_hostname norns`  
`sudo raspi-config`  
    (change locale, timezone, and wifi country in the "Localization" menu)  
    (change password here as well to  ***(sleep)***  )

`sudo reboot`  

Note: if the following `@norns.local` addressing does not work for you, BonJour/ZeroConf may not be working on your system (it's not a default install on Windows). Use the IP address instead.

`ssh pi@norns.local`  
`sudo passwd root` ***(sleep)***  
`sudo nano /etc/ssh/sshd_config`  
 ***(uncomment the line for "PermitRootLogin" and change "prohibit-password" to "yes")***  
`sudo reboot`  

`ssh root@norns.local`  
`usermod -l we -d /home/we -m pi`  
`groupmod --new-name we pi`  
`exit`  
`ssh we@norns.local`  

`sudo passwd -l root` ***(sleep)***  
`sudo nano /etc/sudoers.d/010_pi-nopasswd` ***(change pi to we)***  
`sudo reboot`  

## Linux & Kernel

### Run updates install git, build dependencies, and compile the linux kernel

This installs some required packages and builds the Raspberry Pi kernel modules. 

Reminder: the password is now ***sleep***  

    ssh we@norns.local
	
	sudo apt update -y      
    sudo apt-get dist-upgrade -y
	sudo apt-get install git bc vim bison flex libssl-dev i2c-tools libncurses5-dev -y
	sudo apt-get install raspberrypi-kernel-headers
 	
Then reboot, reconnect and continue...  
    
    cd ~
    git clone https://github.com/okyeron/fates.git

on pi3/Buster 

    cd /home/we/fates/install/norns/scripts && ./fates_prepare_rpi3buster.sh

on pi4

    cd /home/we/fates/install/norns/scripts && ./fates_prepare_rpi4.sh

Answer `m` when prompted for new modules - specifically the SSD1322 module.

Or...  
if the install process shows the `menuconfig` interface:  
Navigate to enable the ssd1322 driver, check to be sure it's enabled with `<M>`
```
##        Device Drivers  ---> Staging Drivers ---> Support for small TFT LCD display modules  --->
##        <M>   SSD1322 driver
```    

If you have a pi4 and are using an HDMI monitor, you will want to disconnect the HDMI monitor cable and do the following via SSH. 

### Testing the ssd1322 OLED
Now we're going to test the OLED display. If your soldering is fine and if the kernel has been built correctly, you should see the console displayed on the OLED screen but first we need to do this :

    ssh we@norns.local
    sudo modprobe fbtft_device custom name=fb_ssd1322 width=128 height=64 speed=16000000 gpios=reset:4,dc:17 rotate=180

pi3  

    con2fbmap 1 1

pi4 - should show console as soon as you execute `modprobe`

You can also use `lsmod` to check if the `fbtft_device` has loaded properly. Which should look something like:

	fb_ssd1322             16384  0
	fbtft_device           49152  0
	fbtft                  45056  2 fbtft_device,fb_ssd1322

`con2fbmap 1 0` will map the console back to HDMI (fb0) if you need that.
    
Note - The OLED will continue to display whatever is on it until you reboot again.

## Norns

    cd /home/we/fates/install/norns/scripts &&./fates_packages.sh

Answer ***yes (y)*** to "enable realtime priority"

Keep an eye out for any errors while installing packages here. If you get any errors, you could try this step again.

When this finishes, you will be disconnected and the pi will reboot. 

When the pi has rebooted, reconnect via SSH.

pi3/Buster

    cd /home/we/fates/install/norns/scripts &&./fates_install_pi3buster.sh

pi4/Buster

    cd /home/we/fates/install/norns/scripts &&./fates_install_pi4.sh
    
Answer yes (Y) to install prompts.

The pi will reboot. When it restarts you should see the norns menu interface. The screen will probably say `error: SUPERCOLLIDER FAIL`. Ignore this for the moment as it should get fixed in the next step. 

## Wifi network  

Reconnect via SSH

    cd /home/we/fates/install/norns/scripts &&./fates_networkmanager.sh

Answer yes (Y) to install prompts.

This installs network manager and changes your previous wpa_supplicant wifi setup. After the following steps, you'll likely get a new IP address.
 
After reboot, on the Raspberry pi, using the OLED screen navigate to SYSTEM > WIFI and add your network manually.

This is a bit of a hassle to do manually, but you only have to do it once and it should ensure your WIFI works properly from here on out.

## Audio configuration 

    ssh we@norns.local
    
    amixer controls
	amixer cset numid=1 123 #Master Playback Volume
    amixer cset numid=3 29  #Capture Volume
    amixer cset numid=4 on  #Line Capture Switch 
    amixer cset numid=7 0   #Sidetone Playback Volume
    amixer cset numid=13 on #Output Mixer HiFi  
    sudo alsactl store

you can also view these settings with

	alsamixer

## Set your timezone 

    sudo raspi-config
    
	(go to "Localization Options" menu item and select "Change Timezone")  

## Norns documentation

https://monome.org/docs/norns/

Be sure to check out the section on the [web-based editor maiden](https://monome.org/docs/norns/#maiden). 

Maiden is extremely useful to get debug information if something is going wrong with the norns software. Its interface is arranged into a left sidebar FILE navigator and a right split editor, where the top is the EDITOR and the bottom is the REPL (read-eval-print-loop).

## Norns scripts  

You can find scripts/patches for norns on the [lines forum](https://llllllll.co/c/library)

Scripts are installed at `~/dust/code` The easiest way to install is by using `git clone` from the linux command line as most of the scripts are hosted on github.

for example

```
cd ~/dust/code
git clone https://github.com/justmat/foulplay.git
```
will install the Foulplay script by @justmat

## Norns extras

There are 2 extra scripts installed at in the `~/norns` directory - `restart.sh` and `stopall.sh`. These can be used to restart all of the norns software components or stop all those processes (matron, crone/supercollider, JACK, and maiden).

*These install instructions are based on the work of Tehn, Nordseele, Thetechnobear among others. Thank you!*

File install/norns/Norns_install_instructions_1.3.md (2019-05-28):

# Installing Norns on Fates
***Fates v1.3 pcb only.***

## Preparing the Raspberry PI

### Download raspbian stretch lite
https://www.raspberrypi.org/downloads/raspbian/  

### Flash raspbian lite to the sdcard
Use balenaEtcher - https://www.balena.io/etcher/ for this.

### SSH configuration

 Create a **wpa-supplicant.conf** file for your network and copy the file to the root of the ***boot*** volume

    country=US #(your country)
    update_config=1
    ctrl_interface=DIR=/var/run/wpa_supplicant GROUP=netdev
    network={
      scan_ssid=1
      ssid="Name of your router"
      psk="Your key"
      key_mgmt=WPA-PSK
    }

Open a terminal and type paste the following commands, one line at a time:

    cd /Volumes && ls
    cd boot && touch ssh

Move the **wpa-supplicant.conf** file you've created to the root of the SD card and then unmount the sd card.

### Put the SD card in the Raspberry Pi and boot

Find the IP of your Raspberry Pi using a software like [Lanscan](https://itunes.apple.com/us/app/lanscan/id472226235) (on MacoS) and then 
   generate a key (replace XX with the IP of the RPI).  
Open a terminal and enter the following command (XX is the last two digits of the PI's IP).  
`ssh-keygen -R 192.168.1.XX`

Connect via SSH. `ssh pi@192.168.1.XX` The password is ***raspberry***

### RPI adjustments
Enter the following commands in a terminal, edit if needed (country etc).

`sudo raspi-config nonint do_hostname norns`  
`sudo raspi-config nonint do_spi 0`  
`sudo raspi-config nonint do_expand_rootfs`  
`sudo raspi-config` (change wifi country in the "Localization" menu, this is crucial)  
`sudo su`  
`passwd pi` ***(sleep)***  
`sudo reboot`  
`ssh keygen -R norns.local`  
`sudo passwd root` ***(sleep)***  
`sudo nano /etc/ssh/sshd_config` ***("PermitRootLogin" needs to be set to "yes" and uncomment the line)***  
`sudo reboot`  
`ssh root@norns.local`  
`usermod -l we -d /home/we -m pi`   
`groupmod --new-name we pi`  
`exit`  
`ssh we@norns.local`  
`sudo passwd -l root` ***(sleep)*** 
`sudo nano /etc/sudoers.d/010_pi-nopasswd` ***(change pi to we)***  
`sudo reboot`

## Linux & Kernel

### Run updates install git, build dependencies, etc
Reminder: the password is ***sleep***  

    ssh we@norns.local
	sudo apt-get update
    sudo apt-get dist-upgrade -y
    sudo apt-get install vim git bc i2c-tools -y
    
    git clone https://github.com/okyeron/fates.git
    cd /home/we/fates/install/norns/scripts && ./fates_prepare.sh

### Testing the ssd1322
Now we're going to test the display. If your soldering is fine and if the kernel has been built correctly, you should see the console displayed on the OLED screen but first we need to do this :

    sudo modprobe fbtft_device custom name=fb_ssd1322 width=128 height=64 speed=16000000 gpios=reset:4,dc:17
    con2fbmap 1 1

## Norns
    cd /home/we/fates/install/norns/scripts &&./fates_packages.sh

You will be disconnected and the device will reboot. Reconnect in a new window.  

    cd /home/we/fates/install/norns/scripts &&./fates_install_1.3.sh
Answer ***yes (y)*** to "enable realtime priority"

## Wifi network  
*Do this manually, too risky to put it in the script.*

    ssh we@norns.local
    sudo apt install network-manager
    sudo cp /home/we/fates/install/norns/files/interfaces /etc/network/interfaces
    sudo mv /etc/wpa_supplicant/wpa_supplicant.conf /etc/wpa_supplicant/wpa_supplicant_bak.conf

And reboot (with command line if possible).  
On the Raspberry pi, navigate to System -> Wifi and add your network manually.

## Audio configuration
*(this part needs to be tested once again)*

    ssh we@norns.local
    amixer controls
    amixer cset numid=13 on #Output Mixer HiFi  
    amixer cset numid=4 on #line in  
    sudo alsactl store  
    amixer cset numid=3 0%

    sudo reboot

*N.B: These install instructions are based on the work of Tehn, Nordseele, The Technobear among others. Thank you!*

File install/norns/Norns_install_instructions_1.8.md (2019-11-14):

# Installing Linux and Norns on Fates (full install)
***For Fates v1.8 pcb or later***

DO NOT USE THIS IF YOU HAVE DOWNLOADED ONE OF THE FATES DISK IMAGES

This is a full "from scratch" install of everything.
 
## Preparing the Raspberry PI

### Download Raspbian Buster Lite (for pi3 or pi4) 

https://www.raspberrypi.org/downloads/raspbian/  

### Flash raspbian lite to the sdcard
Use balenaEtcher - https://www.balena.io/etcher/ for this.

When etcher is finished it will unmount your SD card. Remove the SD card and re-insert/mount it in your computer for the next steps.

### SSH and WiFi configuration

The following assumes a "headless" situation without a keyboard or monitor attached to the pi. If you have a keyboard and monitor setup, use `sudo raspi-config` and set up wifi and ssh there. 

Alternately you can connect to the pi over ethernet and then setup wifi with `raspi-config`. NOTE that you still need the `ssh` file to do this.

Create an empty file named `ssh` (lowercase, and be sure there's no file extension)

Next create a `wpa_supplicant.conf` file with your local wifi network settings. Change the country, router name, and key in the example below.

    country=US #(your country)
    update_config=1
    ctrl_interface=DIR=/var/run/wpa_supplicant GROUP=netdev
    network={
      scan_ssid=1
      ssid="Name of your router"
      psk="Your key"
      key_mgmt=WPA-PSK
    }

Then copy the **wpa_supplicant.conf** and **ssh** files you've created to the root of the ***boot*** volume on the SD card and then unmount the card.

### Put the SD card in the Raspberry Pi and boot

Find the IP of your Raspberry Pi using a software like [Lanscan](https://itunes.apple.com/us/app/lanscan/id472226235) (on MacoS)
   
Or if you have a keyboard and HDMI monitor plugged into the pi, login and use `ifconfig` to get your IP address `inet` (you want the one listed under `wlan0`).

(Optional)
Then you can generate an SSH key (replace XX below with the IP of the RPI).  
Open a terminal and enter the following command (XX is the last two digits of the PI's IP).  
`ssh-keygen -R 192.168.1.XX`

Connect via SSH. `ssh pi@192.168.1.XX` The default password is ***raspberry***

`ssh pi@raspberrypi.local` may also work if you have BonJour/ZeroConf available.

### RPI adjustments
Enter the following commands in a terminal, edit if needed (country etc).

Note - a fair bit of this setup is to get the pi to behave exactly like a hardward norns unit (default username/password, etc.)

`sudo raspi-config nonint do_spi 0`  
`sudo raspi-config nonint do_i2c 0`  
`sudo raspi-config nonint do_expand_rootfs`  
`sudo raspi-config nonint do_hostname norns`  
`sudo raspi-config`  
    (change locale, timezone, and wifi country in the "Localization" menu)  
    (change password here as well to  ***(sleep)***  )

`sudo reboot`  

Note: if the following `@norns.local` addressing does not work for you, BonJour/ZeroConf may not be working on your system (it's not a default install on Windows). Use the IP address instead.

`ssh pi@norns.local`  
`sudo passwd root` ***(sleep)***  
`sudo nano /etc/ssh/sshd_config`  
 ***(uncomment the line for "PermitRootLogin" and change "prohibit-password" to "yes")***  
`sudo reboot`  

SSH back in as root to modify the default user.

`ssh root@norns.local`  
`usermod -l we -d /home/we -m pi`  
`groupmod --new-name we pi`  
`exit`  

`ssh we@norns.local`  

`sudo passwd -l root` ***(sleep)***  
`sudo nano /etc/sudoers.d/010_pi-nopasswd` ***(change pi to we)***  
`sudo reboot`  

## Linux & Kernel

### Run updates install git, build dependencies, and compile the linux kernel

This installs some required packages and builds the Raspberry Pi kernel modules. 

Reminder: the password is now ***sleep***  

    ssh we@norns.local

	sudo apt update -y
    sudo apt-get dist-upgrade -y
	sudo apt-get install git bc vim bison flex libssl-dev i2c-tools libncurses5-dev -y
	sudo apt-get install raspberrypi-kernel-headers

Then reboot, reconnect and continue...  
    
    cd ~
    git clone https://github.com/okyeron/fates.git

on pi3/Buster 

    cd /home/we/fates/install/norns/scripts && ./fates_prepare_rpi3buster.sh

on pi4

    cd /home/we/fates/install/norns/scripts && ./fates_prepare_rpi4.sh

Answer `m` when prompted for new modules - specifically the SSD1322 module.

Or...  
if the install process shows the `menuconfig` interface:  
Navigate to enable the ssd1322 driver, check to be sure it's enabled with `<M>`
```
##        Device Drivers  ---> Staging Drivers ---> Support for small TFT LCD display modules  --->
##        <M>   SSD1322 driver
```    

If you have a pi4 and are using an HDMI monitor, you will want to disconnect the HDMI monitor cable and do the following via SSH. 

### Testing the ssd1322 OLED
Now we're going to test the OLED display. If your soldering is fine and if the kernel has been built correctly, you should see the console displayed on the OLED screen but first we need to do this :

    ssh we@norns.local
    sudo modprobe fbtft_device custom name=fb_ssd1322 width=128 height=64 speed=16000000 gpios=reset:4,dc:17 rotate=180

pi3  

    con2fbmap 1 1

pi4 - should show console as soon as you execute `modprobe`

You can also use `lsmod` to check if the `fbtft_device` has loaded properly. Which should look something like:

	fb_ssd1322             16384  0
	fbtft_device           49152  0
	fbtft                  45056  2 fbtft_device,fb_ssd1322

`con2fbmap 1 0` will map the console back to HDMI (fb0) if you need that.
    
Note - The OLED will continue to display whatever is on it until you reboot again.

## Norns

For the Norns software install, first we need to install various packages that Norns uses.

    cd /home/we/fates/install/norns/scripts &&./fates_packages.sh

Answer ***yes (y)*** to "enable realtime priority"

Keep an eye out for any errors while installing packages here. If you get any errors, you could try this step again.

When this finishes, you will be disconnected and the pi will reboot. 

When the pi has rebooted, reconnect via SSH and finish the Norns install.

pi3/Buster

    cd /home/we/fates/install/norns/scripts &&./fates_install_pi3buster.sh

pi4/Buster

    cd /home/we/fates/install/norns/scripts &&./fates_install_pi4.sh
    
Answer yes (Y) to install prompts.

The pi will reboot. When it restarts you should see "sparkles" and then the norns menu interface. The screen will probably say `error: SUPERCOLLIDER FAIL`. Ignore this for the moment as it should get fixed in the next step. 

## Wifi network  

Reconnect via SSH
    
    ssh we@norns.local
    cd /home/we/fates/install/norns/scripts &&./fates_networkmanager.sh

Answer yes (Y) to install prompts (if any).

This installs network manager and changes your previous wpa_supplicant wifi setup. After the following steps, you'll likely get a new IP address.
 
After reboot, you should see `NONE` at the top of the screen.

Then use the norns menu to navigate to `SYSTEM > WIFI` and add your WiFi network manually. Then use the `ADD` option to choose your network and enter your password, etc.

This is a bit of a hassle to do manually, but you only have to do it once and it should ensure your WIFI works properly from here on out.

## Audio configuration 

    ssh we@norns.local
    
    amixer controls
	amixer cset numid=1 123 #Master Playback Volume
    amixer cset numid=3 29  #Capture Volume
    amixer cset numid=4 on  #Line Capture Switch 
    amixer cset numid=7 0   #Sidetone Playback Volume
    amixer cset numid=13 on #Output Mixer HiFi  
    sudo alsactl store

you can also view these settings with

	alsamixer

## Set your timezone 

    sudo raspi-config
    
	(go to "Localization Options" menu item and select "Change Timezone")
	(then repeat with "Change WiFi Country")

## Norns documentation

https://monome.org/docs/norns/

Be sure to check out the section on the [web-based editor maiden](https://monome.org/docs/norns/#maiden). 

Maiden is extremely useful to get debug information if something is going wrong with the norns software. Its interface is arranged into a left sidebar FILE navigator and a right split editor, where the top is the EDITOR and the bottom is the REPL (read-eval-print-loop).

## Norns scripts  

You can find scripts/patches for norns on the [lines forum](https://llllllll.co/c/library)

Scripts are installed at `~/dust/code` The easiest way to install is by using `git clone` from the linux command line as most of the scripts are hosted on github.

for example

```
cd ~/dust/code
git clone https://github.com/justmat/foulplay.git
```
will install the Foulplay script by @justmat

## Norns extras

There are 2 extra scripts installed at in the `~/` home directory - `norns-restart.sh` and `norns-stopall.sh`. These can be used to restart all of the norns software components or stop all those processes (matron, crone/supercollider, JACK, and maiden).

*These install instructions are based on the work of Tehn, Nordseele, Thetechnobear among others. Thank you!*

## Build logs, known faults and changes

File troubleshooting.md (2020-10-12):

# Fates - Troubleshooting

### Etcher doesn't work for me

You can also try [ApplePiBaker](https://www.tweaking4all.com/hardware/raspberry-pi/applepi-baker-v2/) if you're on MacOS. Otherwise you may be looking at various arcane `dd` commands.

### Power
- Be sure you are using a good power supply. The Pi 3b+ needs a 5V 2.5A power supply. The Pi 4 requires a 5V 3A power supply. Buy one of the official Raspberry Pi power supplies if you're not sure.

- Be sure you're using a good quality USB-C cable (and it's not just a "charging" cable)

- DO NOT TRY TO POWER FATES FROM YOUR LAPTOP USB-C Ports. Use a dedicated 3A power supply.  

- [Check your input voltages](hardware/Build.md#tip---test-voltage)

### `SUPERCOLLIDER FAIL` error on boot:
- This happens because the Jack Audio system is not starting properly. A number of things can cause this. There is a information and support thread on the "lines" forum [here](https://llllllll.co/t/fates-a-diy-norns-dac-board-for-raspberry-pi/22999?u=okyeron)

- Check the orientation of the 2.2K resistors. They should be horizontal, not vertical.

- Check the 3.3v voltage regulator. This powers the DAC so if it's not right, the DAC won't initialize. See the "check your voltages" link above to test.

### Audio tests

SSH to the pi/fates to conduct these tests. Have your audio outputs and inputs connected to speakers/mixer and a sound source.  

A low level test…  
Firstst stop jack, so we can test the DAC directly with ALSA

`sudo systemctl stop norns-jack.service`  

Now use `aplay` to play a wave file.

`aplay ~/dust/audio/common/waves/01.wav`
this should play a simple clean bell tone

An alternate test is speaker-test  
`speaker-test -t wav -c 2 -l 3 -D hw:0,0`

This will play a female voice saying "front right" and "front left" in each channel 3 times. 

Record 15 seconds of audio from the inputs and save to a .wav file 
`arecord -f dat -vv -V stereo -d 15 ~/audio-test.wav`

Play back the same audio file  
`aplay -vv -V stereo ~/audio-test.wav`

`sudo reboot` to get things back to normal. 

###[Raspberry Pi LED status messages](https://elinux.org/R-Pi_Troubleshooting#Red_power_LED_is_on.2C_green_LED_does_not_flash.2C_nothing_on_display)

### FAQ

See [Frequently Asked Questions](FAQ.md) for other general info

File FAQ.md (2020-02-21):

# Fates - Frequently Asked Questions

### SLEEP

> when i go to SYSTEM - SLEEP. Fates does not turn off, it stays on with ‘sleep’ dimmed on screen.

This is "normal" behavior. SLEEP is actually invoking the `sudo shutdown now` command, so the pi will shut off with this command. However, power is still going to the pi (red led will be lit) and to the display. Thus the display will continue to show the last thing on screen.

When you use SLEEP - Make sure you have a solid red indicator light on the pi (no flashing green) and then disconnect from power.

An inline usb power switch (like one from [CanaKit](https://www.canakit.com/raspberry-pi-4-on-off-power-switch.html)) is very handy to switch power off after shutdown.

### Wake from SLEEP

The norns docs mention this:

> Hold K1 for three seconds. Be still, and norns will awaken.

This is a norns hardware only feature and will not work on Fates.

To turn Fates on, just plug into power (or use a switch as mentioned above)

Note - as with norns hardware - **For general shut down use the SLEEP menu function. This fully turns off the device with a proper software shutdown.**

### How do I update?

# Important - regarding norns software updates
If you are on a version of norns before 200218 ***DO NOT*** run the on device SYSTEM > UPDATE from the norns menu. 

You will need to update manually. [See here](https://github.com/fates-project/norns/releases)

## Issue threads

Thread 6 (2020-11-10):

WiFi not connecting

katspaugh, 2020-11-10:
I've tried with two different RPis 3B+ and one RPi 4 – the WiFi isn't connecting to my network. The Hotspot is also not starting.

It does see the available networks but when adding one, nothing happens after entering the password. The green LED flashes for a few seconds and then nothing.

I also have a Norns Shield and it connects to the WiFi without any problems.

Any troubleshooting advice?

_Update:_
I've connected to the Pi via ethernet and tried expanding the disk. It gave me an error: "There was an error running option A1 Expand Filesystem". Flashed another SD-card but it's also giving this error.

It can't write any files on the SD-card either. That explains at least why the WiFi wasn't connecting: it cannot write the wpa_supplicant file.

_Update 2:_
Fixed by doing the resizing manually via the command-line as per https://github.com/okyeron/fates/blob/master/install/norns/Norns_disk_image_install.md#expand-filesystem
Closing this, hopefully it will help others.

Thanks you so much, @okyeron! I've built the Neotrellis grid and used your laser cutter designs, everything works great. Top notch work! 🙇

Closed 2020-11-10.

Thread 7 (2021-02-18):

Need help implementing the same solution for power for a different board

Pastitas, 2021-02-18:
Hi,
I am currently working on a similar board as your's but for another project (zynthian) and wanted to know if you have any schematic and/or the footprint/3d model for the usb c plug (KUSBX-SL-CS1N14-B) and how you connected it to the pi

thanks in advance, also interested into the dac/adc schematic but i understand that you wouldn't want to share that one

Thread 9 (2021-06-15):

MISSING: Fates disk img for Raspberry Pi 4b

stolcy, 2021-06-15:
Hi,

Are you able to reupload the disk image file for Pi4b? The download link is currently broken.

Closed 2021-06-15.

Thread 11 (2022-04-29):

Is DIN Midi In/out using UART possible ?? Ble and AppleMIDI also?

fabiendostie, 2022-04-29:
If I use a protected diy midi in circuit using a diode + resistance and H11L1?
and
Is ble midi or appleMIDI even possible on a RPI4b+?

Thanks

Closed 2022-07-19.

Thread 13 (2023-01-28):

fates does not power up after firmware update

DarkSines, 2023-01-28:
I recently got a fully functional fates norns that had old firmware (2019). the first thing I did when i received it was removed the sdhc card and upload the latest norns firmware (dec '22) to the sdhc card with etcher. the file image transfer was successful. I then inserted the card and plugged fates into a power source. I first used the usb output of a power strip, my macbook pro, a macbook air power adapter, and an ipad power adapter. none of these have powered up the fates. in each instance, a red led on the front of the fates lights up and the green led blinks four times consecutively or flashes erratically, while the red led is constant.

I have searched lines for a solution to no avail. I have read through the norns documents and troubleshooting on monome.org. I am unsure how to proceed. Any resources you can send or ideas about what i did wrong, or have not done yet, would be much appreciated.

My ideas were to 1. purchase the suggested power adapter for norns from adafruit, 2.  get a new sdhc card and upload the firmware using the raspberry pi imager instead of etcher, and 3,  if i have damaged the unit by using a power adapter that sent too much voltage, have it repaired and purchase the necessary parts to do so. I felt it necessary to ask the developer before potentially causing additional issues.

I did not power on the norns with the 2019 firmware or connect it to wifi and maiden before overwriting the 2019 firmware with the latest firmware.

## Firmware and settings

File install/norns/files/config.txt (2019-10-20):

# For more options and information see
# http://rpf.io/configtxt
# Some settings may impact device functionality. See link above for details

# uncomment if you get no picture on HDMI for a default "safe" mode
#hdmi_safe=1

# uncomment this if your display has a black border of unused pixels visible
# and your display can output without overscan
#disable_overscan=1

# uncomment the following to adjust overscan. Use positive numbers if console
# goes off screen, and negative if there is too much border
#overscan_left=16
#overscan_right=16
#overscan_top=16
#overscan_bottom=16

# uncomment to force a console size. By default it will be display's size minus
# overscan.
#framebuffer_width=1280
#framebuffer_height=720

# uncomment if hdmi display is not detected and composite is being output
#hdmi_force_hotplug=1

# uncomment to force a specific HDMI mode (this will force VGA)
#hdmi_group=1
#hdmi_mode=1

# uncomment to force a HDMI mode rather than DVI. This can make audio work in
# DMT (computer monitor) modes
#hdmi_drive=2

# uncomment to increase signal to HDMI, if you have interference, blanking, or
# no display
#config_hdmi_boost=4

# uncomment for composite PAL
#sdtv_mode=2

#uncomment to overclock the arm. 700 MHz is the default.
#arm_freq=800

# Uncomment some or all of these to enable the optional hardware interfaces
dtparam=i2c_arm=on
dtparam=spi=on
dtparam=i2s=on
dtoverlay=i2s-mmap

# Uncomment this to enable the lirc-rpi module
#dtoverlay=lirc-rpi

# Additional overlays and parameters are documented /boot/overlays/README

enable_uart=1

# DAC audio
dtoverlay=rpi-proto

# Buttons and encoders
#dtoverlay=fates-buttons-encoders

# Alternate overlay for 4 encoders
dtoverlay=fates-buttons-4encoders


# Screen
dtoverlay=fates-ssd1322,rotate=180

# How much memory in MB to assign to the GPU in MB
# Lowest possible value is 16
#gpu_mem=16

# Enable audio (loads snd_bcm2835)
dtparam=audio=off

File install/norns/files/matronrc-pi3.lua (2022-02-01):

function init_norns()
  _boot.add_io('screen:fbdev', {dev='/dev/fb1'})
  _boot.add_io('keys:gpio',    {dev='/dev/input/by-path/platform-keys-event'})
  _boot.add_io('enc:gpio',     {dev='/dev/input/by-path/platform-soc:knob1-event', index=1})
  _boot.add_io('enc:gpio',     {dev='/dev/input/by-path/platform-soc:knob2-event', index=2})
  _boot.add_io('enc:gpio',     {dev='/dev/input/by-path/platform-soc:knob3-event', index=3})
  _boot.add_io('enc:gpio',     {dev='/dev/input/by-path/platform-soc:knob4-event', index=4})
end

function init_desktop()
  -- desktop window
  _boot.add_io('screen:sdl', {})
  -- _boot.add_io('input:sdl', {})

  -- i/o via maiden
  -- _boot.add_io('screen:json', {})
  -- _boot.input_add('web_input', 'json', {})
end

init_norns()

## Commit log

2019-06-16 separate bom from readme
2019-06-16 update bom
2019-06-16 update/move bom
2019-06-21 update encoder dts
2019-07-11 Add pi4 files
    [config4.txt]
2019-07-23 changes for 1.7 and pi4
    [config.txt, config4.txt]
2019-07-23 updating BOM
2019-07-23 fix 1.7 board images
2019-07-29 update alternates in bom
2019-07-29 bom update for encoders
2019-08-02 udpate file perms
    [config.txt, config4.txt]
2019-08-05 add 4encoders dts
    [config.txt, config4.txt]
2019-08-13 update bom for spacers
2019-08-19 bom update
2019-08-19 update board pic
2019-08-19 more bom updates
2019-08-19 bom update for screws
2019-08-23 update bom, panels
    [fates-panels-v1.8-3enc.dxf, fates-panels-v1.8-4enc.dxf]
2019-08-23 bom formatting
2019-08-23 bom updates
2019-08-24 update spacers
2019-08-25 bom bom bom
2019-08-25 add case design
2019-08-30 bom and case files
    [fates-panels-v1.8-3enc.dxf, fates-panels-v1.8-4enc.dxf]
2019-09-08 Add thruhole bom
2019-09-09 update thruhole bom
2019-09-09 bom diddly bom
2019-09-09 bom bom
2019-09-12 bom typos
2019-09-19 build/bom updates
2019-09-22 bom fix
2019-09-22 update case files
2019-09-24 bom fix spacer list, move start/stop scripts
2019-10-01 updated case files
2019-10-04 bom and build notes
2019-10-05 bom update for alt gpio header
2019-10-05 fix spacer list
2019-10-05 fix standoff links
2019-10-14 bom upates
2019-10-15 Update Build.md
    Fixed up image for 18p capacitors
2019-10-17 voltages pix
2019-10-18 add case guide
2019-10-18 case guide
2019-10-18 update case build info
2019-10-18 fix resistor numbers on bom
2019-10-20 default to 4encoders
    [config.txt, config4.txt]
2019-11-19 Warning for power
2019-12-14 update power switch link
2019-12-24 add device_monitor hack
2019-12-24 add crone fix to device hack
2020-01-27 device_monitor fix for crow
2020-01-27 device_monitor fix for arc clone
2020-12-03 dynamic framebuffer fix
